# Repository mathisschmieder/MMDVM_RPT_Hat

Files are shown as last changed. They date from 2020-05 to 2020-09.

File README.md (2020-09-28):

# MMDVM_RPT_Hat
MMDVM_RPT_Hat for the Raspberry Pi

This project provides a Raspberry Pi Hat for the [MMDVM](https://github.com/g4klx/MMDVM).

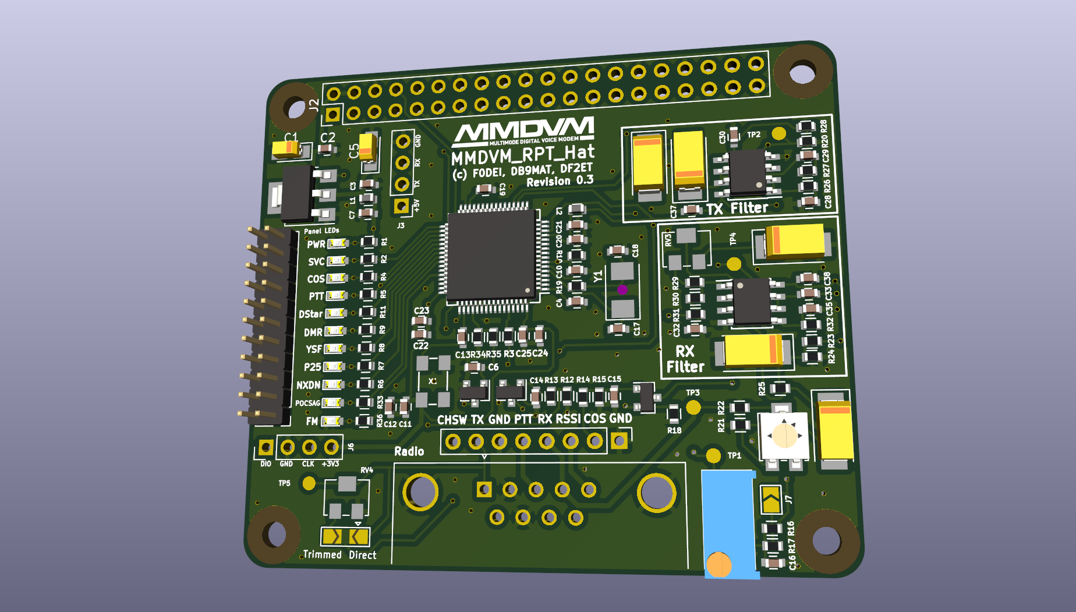
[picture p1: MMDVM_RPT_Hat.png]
PCB


## Revisions

### Revision 0.1
First PCB built for testing purposes.

### Revision 0.2
A second MOSFET transitor has been added to allow for channel switching by the MMDVM.

### Revision 0.3
Another LED was added for the latest implementation of FM mode.

## BOM
* The BOM for the rev0.1 board is available as [Mouser cart](https://www.mouser.com/ProjectManager/ProjectDetail.aspx?AccessID=13f81d64ff).
* [Mouser cart](https://www.mouser.com/ProjectManager/ProjectDetail.aspx?AccessID=fb0666986e) for rev0.2 board.
* Here is the [Mouser cart](https://www.mouser.com/ProjectManager/ProjectDetail.aspx?AccessID=3737004138) for the revision 0.3.

## License
This project is released under the Creative Commons Attribution-NonCommercial-ShareAlike 3.0 (CC-BY-NC-SA 3.0, https://creativecommons.org/licenses/by-nc-sa/3.0/) license. You may edit and share it as you like, as long as credit is given and the license is not changed. You can build as many boards for you and your friends as you like and you can even sell it to them to cover your costs, **however it is strictly forbidden to turn this into a commercial product! You are not allowed to build and sell these boards for profit!**

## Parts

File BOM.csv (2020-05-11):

Refs | Value | Footprint | QTY | MFR | MPN | SPR | SPN
C37;C38;C2;C3;C21;C22;C24;C10;C13;C12;C16;C4 | 100n | Capacitors_SMD:C_0603 | 12 | KEMET | C0603T104K3RALTU | Mouser | 80-C0603T104K3RALTU
C32;C28 | 10n | Capacitors_SMD:C_0603 | 2 | KEMET | C0603C103K2RECTU | Mouser | 80-C0603C103K2REC
C7 | 10u | Capacitors_SMD:C_0603 | 1 | KEMET | C0603C106M7PACTU | Mouser | 80-C0603C106M7P
C35;C30 | 1n | Capacitors_SMD:C_0603 | 2 | KEMET | C0603S102K4RACTU | Mouser | 80-C0603S102K4R
C17;C18 | 20p | Capacitors_SMD:C_0603 | 2 | KEMET | C0603C200K4GACTU | Mouser | 80-C0603C200K4G
C33;C29 | 39n | Capacitors_SMD:C_0603 | 2 | KEMET | C0603C393K4RACTU | Mouser | 80-C0603C393K4R
C14;C15;C6 | 470p | Capacitors_SMD:C_0603 | 3 | KEMET | C0603C471K4RACTU | Mouser | 80-C0603C471K4R
C20;C23;C25;C19;C11 | 4u7 | Capacitors_SMD:C_0603 | 5 | Murata Electronics | GRM188R61C475KAAJD | Mouser | 81-GRM188R61C475KAJD
C26;C27;C31;C34;C36 | 47u | Capacitors_Tantalum_SMD:CP_EIA-6032-28_Kemet-C | 5 | AVX | TAJC476K016SNJ | Mouser | 581-TAJC476K016SNJ
C1;C5 | 10u | Capacitors_Tantalum_SMD:CP_Tantalum_Case-A_EIA-3216-18_Reflow | 2 | AVX | F931C106KAA | Mouser | 647-F931C106KAA
J7 | GS2 | Connectors:GS2 | 1
J8 | GS3 | Connectors:GS3 | 1
J1 | Radio | Connectors_DSub:DSUB-9_Male_Horizontal_Pitch2.77x2.84mm_EdgePinOffset4.94mm_Housed_MountingHolesOffset7.48mm | 1 | TE Connectivity / AMP | 1734354-1 | Mouser | 571-1734354-1
Y1 | 8 MHz | Crystals:Crystal_SMD_Abracon_ABM3-2pin_5.0x3.2mm | 1 | ABRACON | ABM3-8.000MHz-D2Y-T | Mouser | 815-ABM3-8-D2Y-T
U2 | STM32F722RETx | Housings_QFP:LQFP-64_10x10mm_Pitch0.5mm | 1 | STMicroelectronics | STM32F722RET6 | Mouser | 511-STM32F722RET6
U3;U4 | MCP6002 | Housings_SOIC:SOIC-8_3.9x4.9mm_Pitch1.27mm | 2 | Microchip Technology | MCP6002-E/SN | Mouser | 579-MCP6002-E/SN
L1 | 10u | Inductors_SMD:L_0603 | 1 | Murata Electronics | LQM18FN100M00D | Mouser | 81-LQM18FN100M00D
L2 | 600R, 500mA | Inductors_SMD:L_0603 | 1 | Wurth Electronics | 742863160 | Mouser | 710-742863160
D3 | COS | LEDs:LED_0603 | 1 | Kingbright | APT1608SYC | Mouser | 604-APT1608SYC
D8 | DMR | LEDs:LED_0603 | 1 | Kingbright | APT1608SYC | Mouser | 604-APT1608SYC
D9 | DSTAR | LEDs:LED_0603 | 1 | Kingbright | APT1608SGC | Mouser | 604-APT1608SGC
D5 | NXDN | LEDs:LED_0603 | 1 | Kingbright | APT1608VBC/D | Mouser | 604-APT1608VBC/D
D6 | P25 | LEDs:LED_0603 | 1 | Kingbright | APT1608SURCK | Mouser | 604-APT1608SURCK
D10 | POCSAG | LEDs:LED_0603 | 1 | Kingbright | APT1608VBC/D | Mouser | 604-APT1608VBC/D
D4 | PTT | LEDs:LED_0603 | 1 | Kingbright | APT1608SURCK | Mouser | 604-APT1608SURCK
D1 | PWR | LEDs:LED_0603 | 1 | Kingbright | APT1608SGC | Mouser | 604-APT1608SGC
D2 | SVC | LEDs:LED_0603 | 1 | Kingbright | APT1608SURCK | Mouser | 604-APT1608SURCK
D7 | YSF | LEDs:LED_0603 | 1 | Kingbright | APT1608SECK | Mouser | 604-APT1608SECK
D11 | FM | LEDs:LED_0603 | 1 | Kingbright | APT1608VBC/D | Mouser | 604-APT1608VBC/D
TP3;TP4;TP2;TP5;TP1 | TEST | Measurement_Points:Measurement_Point_Round-SMD-Pad_Small | 5
J6 | STLink | Pin_Headers:Pin_Header_Straight_1x04_Pitch2.54mm | 1 | Wurth Electronics | 61300411121 | Mouser | 710-61300411121
J3 | Serial Display | Pin_Headers:Pin_Header_Straight_1x04_Pitch2.54mm | 1 | Wurth Electronics | 61300411121 | Mouser | 710-61300411121
J5 | Radio | Pin_Headers:Pin_Header_Straight_1x08_Pitch2.54mm | 1 | Wurth Electronics | 61300811121 | Mouser | 710-61300811121
J4 | Panel LEDs | Connector_PinHeader_2.00mm:PinHeader_2x11_P2.00mm_Vertical | 1 | Samtec | MTMM-111-09-L-D-380 | Mouser | 200-MTMM11109LD380
J2 | Raspberry_Pi_2_3 | Pin_Headers:Pin_Header_Straight_2x20_Pitch2.54mm | 1 | Harwin | M20-7832046 | Mouser | 855-M20-7832046
RV3 | 100k | Potentiometer_SMD:Potentiometer_Bourns_3214W_Vertical | 1 | Bourns | 3214W-1-104E | Mouser | 652-3214W-1-104E
RV4 | 200k | Potentiometer_SMD:Potentiometer_Bourns_3214W_Vertical | 1 | Bourns | 3214W-1-204E | Mouser | 652-3214W-1-204E
RV2 | 10k | Potentiometer_SMD:Potentiometer_Bourns_3314G_Vertical | 1 | Bourns | 3314G-1-103E | Mouser | 652-3314G-1-103E
RV1 | POT | Potentiometers:Potentiometer_Trimmer_Bourns_3296Y | 1 | Bourns | 3296Y-1-104LF | Mouser | 652-3296Y-1-104LF
R20;R3;R10 | 10k | Resistors_SMD:R_0603 | 3 | Panasonic | ERJ-PB3B1002V | Mouser | 667-ERJ-PB3B1002V
R19;R15 | 1M | Resistors_SMD:R_0603 | 2 | Panasonic | ERJ-3EKF1004V | Mouser | 667-ERJ-3EKF1004V
R21 | 1k | Resistors_SMD:R_0603 | 1 | Panasonic | ERJ-3EKF1001V | Mouser | 667-ERJ-3EKF1001V
R1;R2;R4;R5;R6;R7;R8;R9;R11;R33;R36 | 1k5 | Resistors_SMD:R_0603 | 11 | Panasonic | ERJ-3EKF1501V | Mouser | 667-ERJ-3EKF1501V
R22 | 20k | Resistors_SMD:R_0603 | 1 | Panasonic | ERJ-3EKF2002V | Mouser | 667-ERJ-3EKF2002V
R25;R23;R24 | 22k | Resistors_SMD:R_0603 | 3 | Panasonic | ERJ-P03F2202V | Mouser | 667-ERJ-P03F2202V
R29 | 30k | Resistors_SMD:R_0603 | 1 | Panasonic | ERJ-3EKF3002V | Mouser | 667-ERJ-3EKF3002V
R13;R14;R35 | 330 | Resistors_SMD:R_0603 | 3 | Panasonic | ERJ-U03F3300V | Mouser | 667-ERJ-U03F3300V
R16;R12;R18;R34 | 47k | Resistors_SMD:R_0603 | 4 | Panasonic | ERJ-3EKF4702V | Mouser | 667-ERJ-3EKF4702V
R31;R32;R27;R28;R17 | 4k7 | Resistors_SMD:R_0603 | 5 | Panasonic | ERJ-3EKF4701V | Mouser | 667-ERJ-3EKF4701V
R30;R26 | 5k1 | Resistors_SMD:R_0603 | 2 | Panasonic | ERJ-3EKF5101V | Mouser | 667-ERJ-3EKF5101V
U1 | LD1117S33TR | TO_SOT_Packages_SMD:SOT-223-3_TabPin2 | 1 | STMicroelectronics | LD1117S33TR | Mouser | 511-LD1117S33
Q2 | 2N7002 | TO_SOT_Packages_SMD:SOT-23 | 1 | ON Semiconductor / Fairchild | 2N7002 | Mouser | 512-2N7002
Q1;Q3 | IRLML2060 | TO_SOT_Packages_SMD:SOT-23 | 2 | Infineon Technologies | IRLML2060TRPBF | Mouser | 942-IRLML2060TRPBF
X1 | TCXO | lib:FOX-924B | 1 | Fox | FOX924B-12 | Mouser | 559-FOX924B-12

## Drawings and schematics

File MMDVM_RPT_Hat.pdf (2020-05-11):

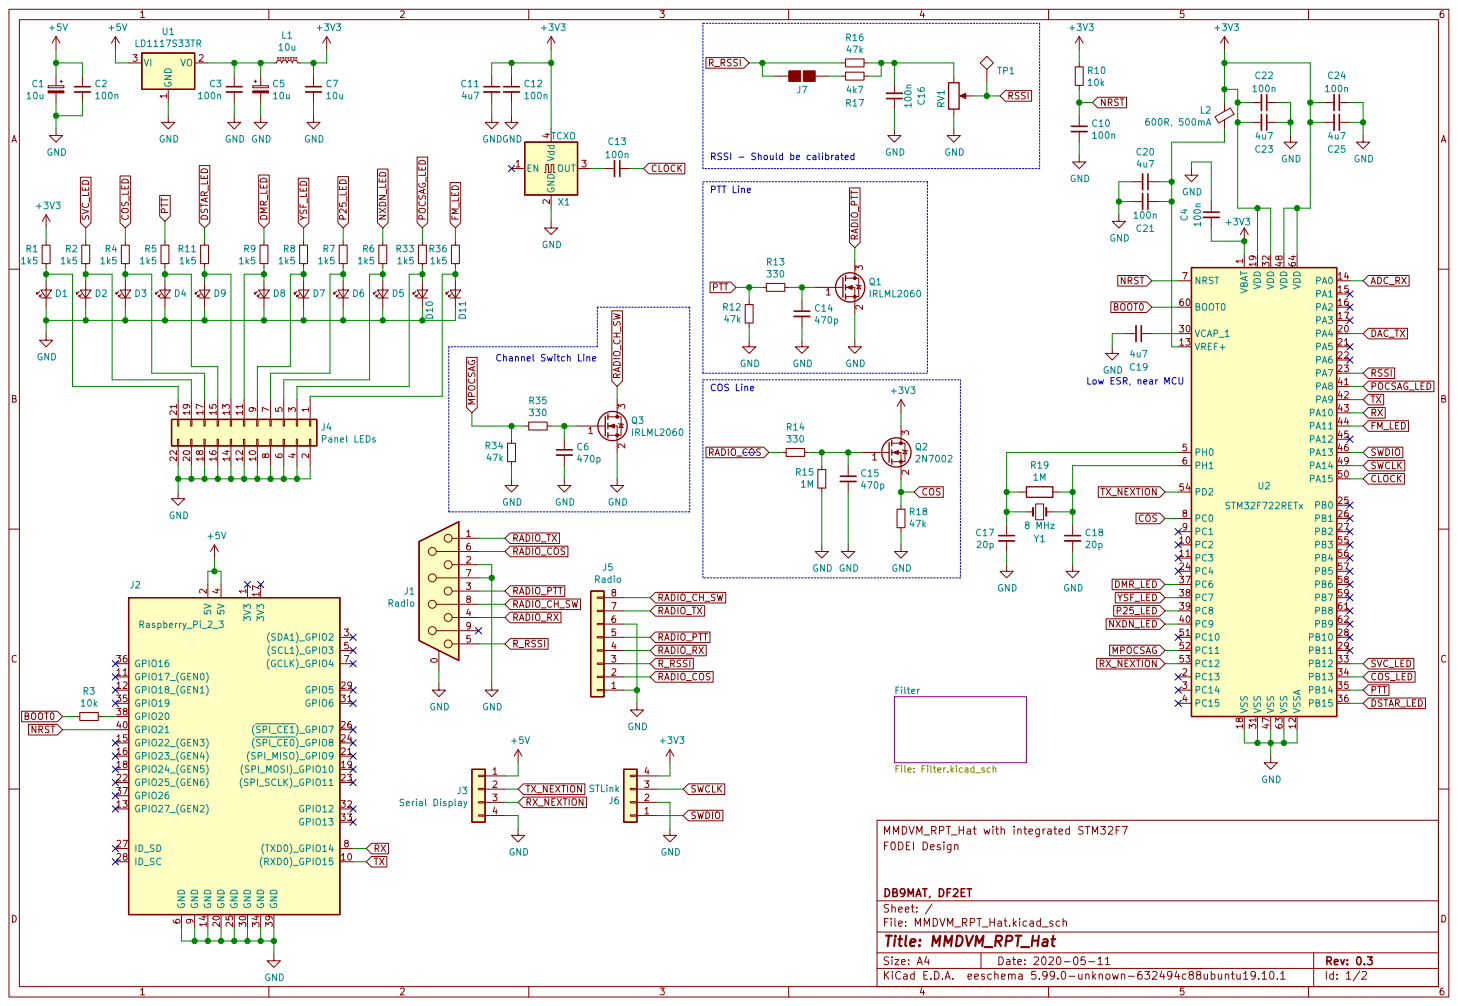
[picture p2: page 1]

1 PC2 10 PC3 11 VSSA 12 VREF+ 13 PA0 14 PA1 15 PA2 16 PA3 17 VSS 18 VDD 19 PC13 2 PA4 20 PA5 21 PA6 22 PA7 23 PC4 24 PB0 25 PB1 26 PB2 27 PB10 28 PB11 29 PC14 3 VCAP_1 30 VSS 31 VDD 32 PB12 33 PB13 34 PB14 35 PB15 36 PC6 37 PC7 38 PC8 39 PC15 4 PC9 40 PA8 41 PA9 42 PA10 43 PA11 44 PA12 45 PA13 46 VSS 47 VDD 48 PA14 49 PH0 5 PA15 50 PC10 51 PC11 52 PC12 53 PD2 54 PB3 55 PB4 56 PB5 57 PB6 58 PB7 59 PH1 6 BOOT0 60 PB8 61 PB9 62 VSS 63 VDD 64 NRST 7 PC0 8 PC1 9 U2 STM32F722RETx 1

Low ESR, near MCU COS Line

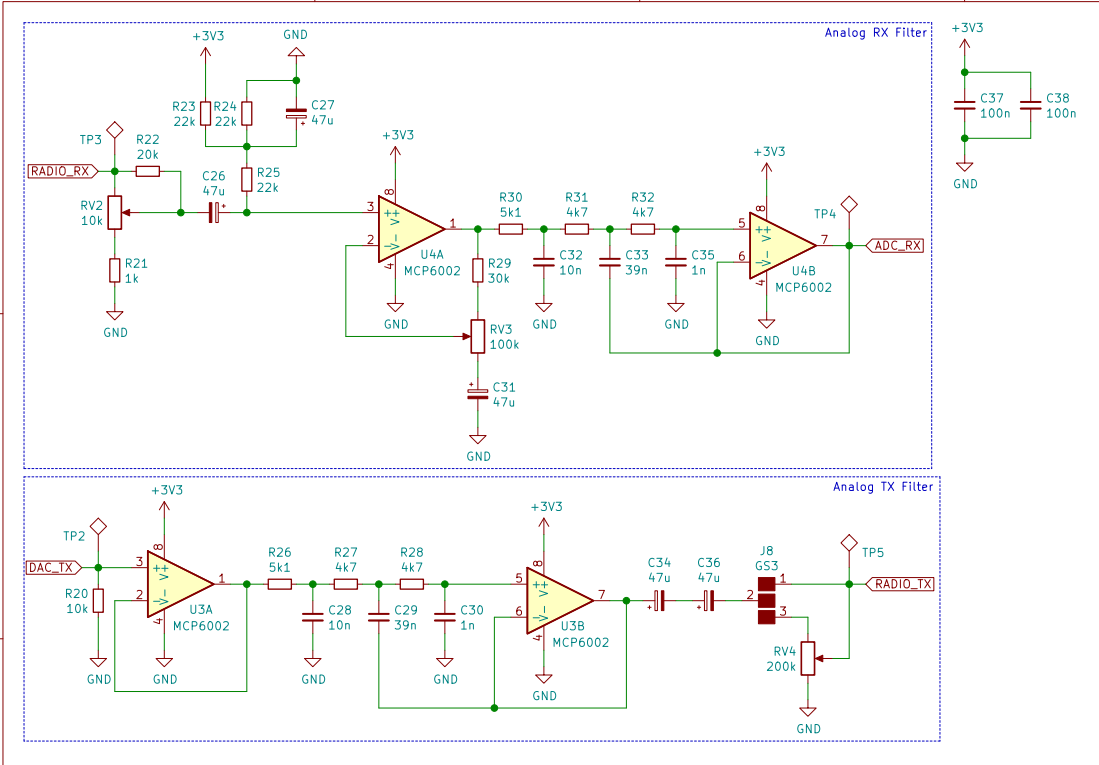
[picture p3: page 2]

File: Filter.kicad_sch Sheet: /Filter/ DB9MAT

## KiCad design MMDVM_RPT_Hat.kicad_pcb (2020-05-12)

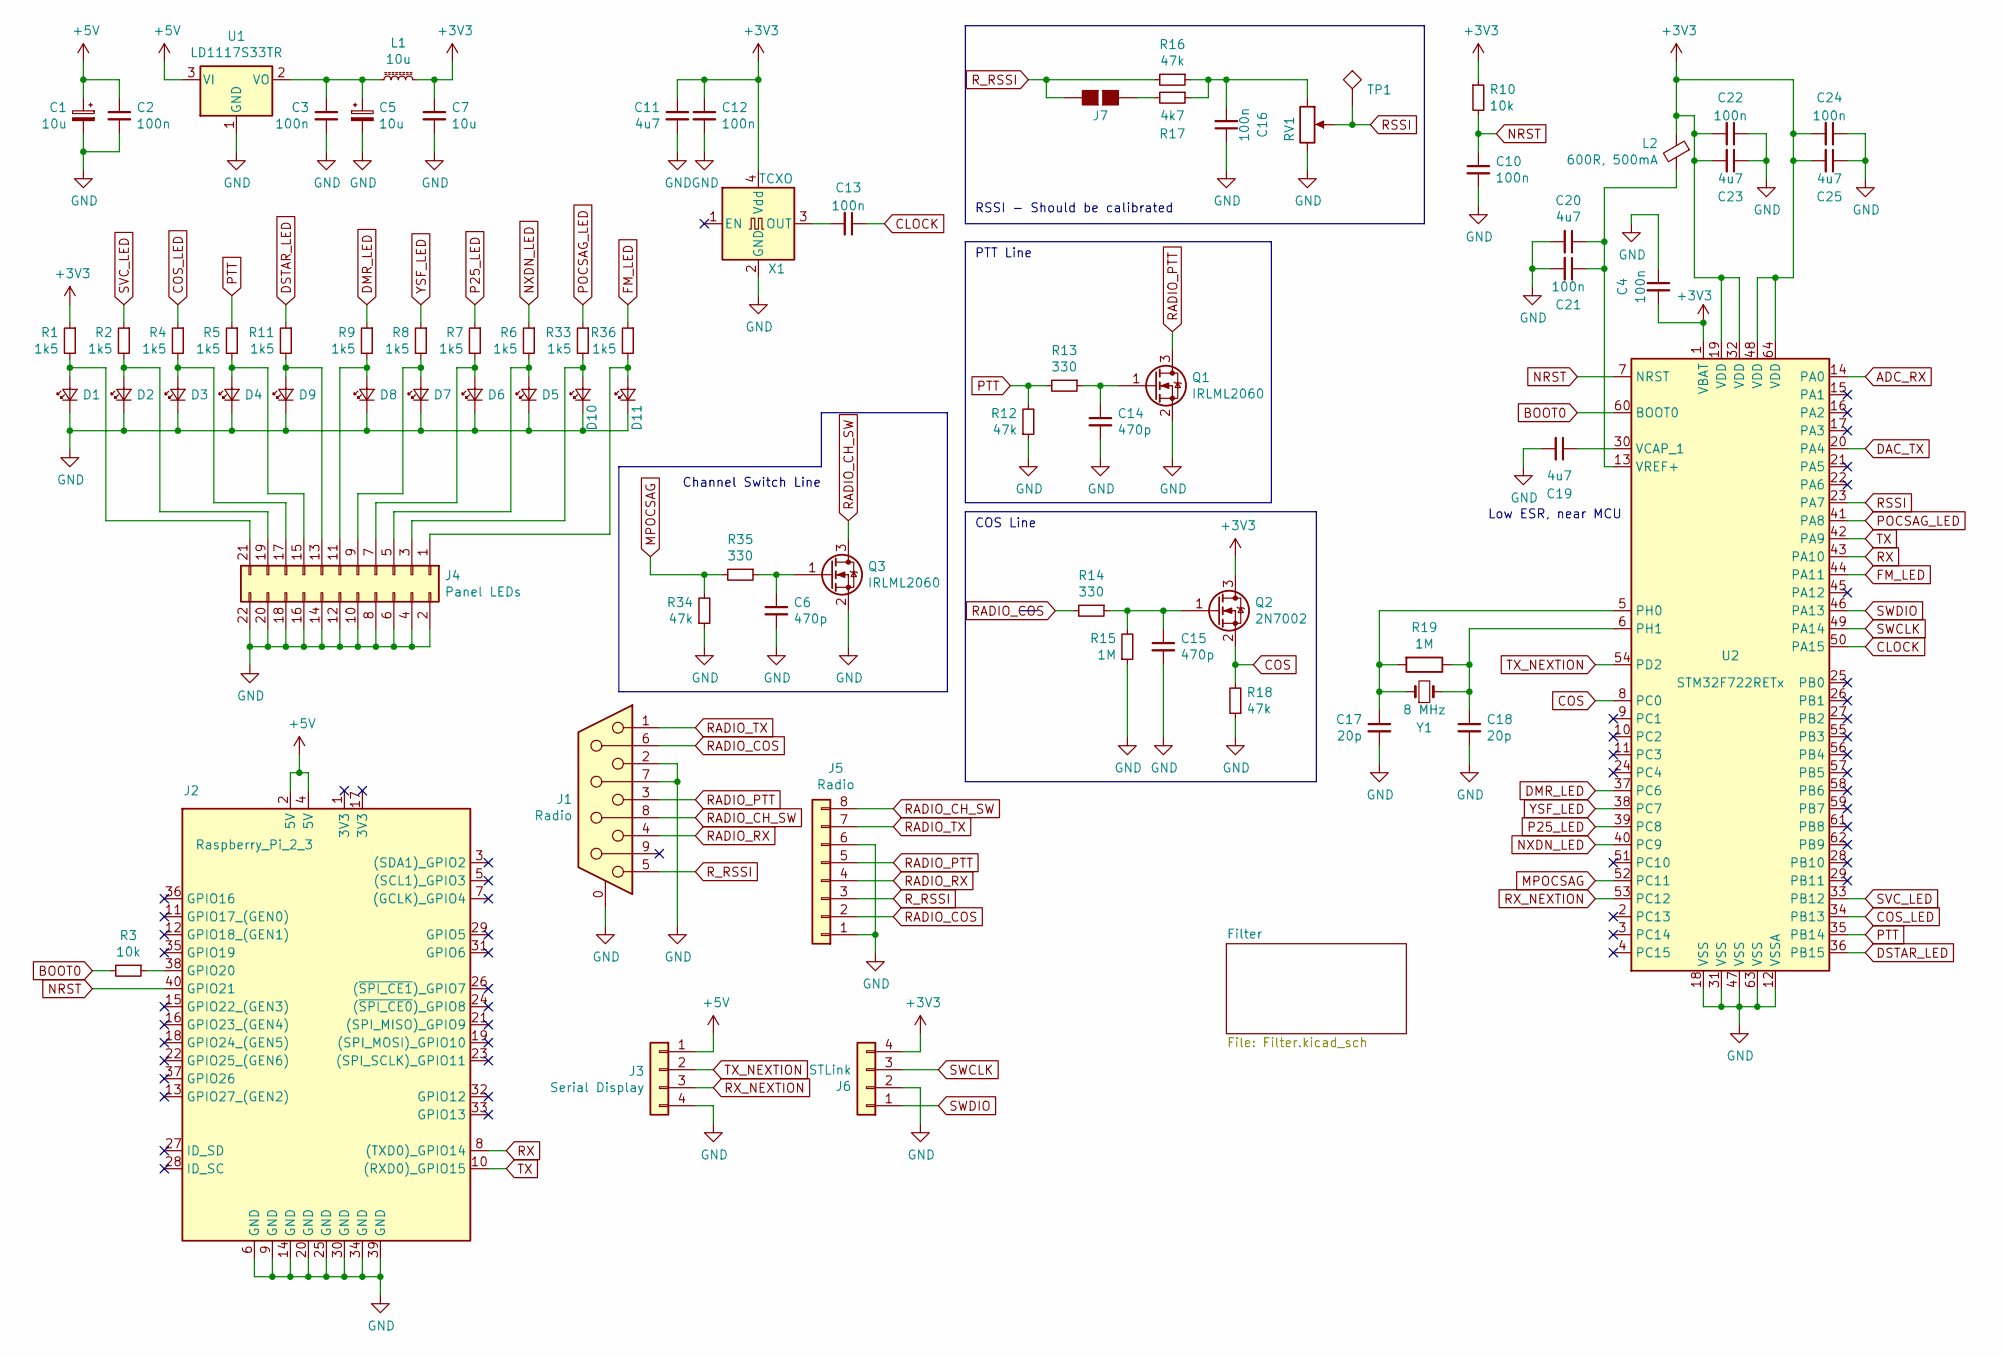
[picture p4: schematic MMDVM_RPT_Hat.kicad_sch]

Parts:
C1, C5: 10u; CP_Tantalum_Case-A_EIA-3216-18_Reflow; MPN F931C106KAA
C2, C3, C4, C10, C12, C13, C16, C21, C22, C24: 100n; C_0603; MPN C0603T104K3RALTU
C6, C14, C15: 470p; C_0603; MPN C0603C471K4RACTU
C7: 10u; C_0603; MPN C0603C106M7PACTU
C11, C19, C20, C23, C25: 4u7; C_0603; MPN GRM188R61C475KAAJD
C17, C18: 20p; C_0603; MPN C0603C200K4GACTU
D1: PWR; LED_0603; MPN APT1608SGC
D2: SVC; LED_0603; MPN APT1608SURCK
D3: COS; LED_0603; MPN APT1608SYC
D4: PTT; LED_0603; MPN APT1608SURCK
D5: NXDN; LED_0603; MPN APT1608VBC/D
D6: P25; LED_0603; MPN APT1608SURCK
D7: YSF; LED_0603; MPN APT1608SECK
D8: DMR; LED_0603; MPN APT1608SYC
D9: DSTAR; LED_0603; MPN APT1608SGC
D10: POCSAG; LED_0603; MPN APT1608VBC/D
D11: FM; LED_0603; MPN APT1608VBC/D
J1: Radio; DSUB-9_Male_Horizontal_Pitch2.77x2.84mm_EdgePinOffset4.94mm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; MPN 1734354-1
J2: Raspberry_Pi_2_3; Pin_Header_Straight_2x20_Pitch2.54mm; MPN M20-7832046
J3: Serial Display; Pin_Header_Straight_1x04_Pitch2.54mm; MPN 61300411121
J4: Panel LEDs; PinHeader_2x11_P2.00mm_Vertical
J5: Radio; Pin_Header_Straight_1x08_Pitch2.54mm; MPN 61300811121
J6: STLink; Pin_Header_Straight_1x04_Pitch2.54mm; MPN 61300411121
J7: GS2
L1: 10u; L_0603; MPN LQM18FN100M00D
L2: 600R, 500mA; L_0603; MPN 742863160
Q1, Q3: IRLML2060; SOT-23; MPN IRLML2060TRPBF
Q2: 2N7002; SOT-23; MPN 2N7002
R1, R2, R4, R5, R6, R7, R8, R9, R11, R33, R36: 1k5; R_0603; MPN ERJ-3EKF1501V
R3, R10: 10k; R_0603; MPN ERJ-PB3B1002V
R12, R16, R18, R34: 47k; R_0603; MPN ERJ-3EKF4702V
R13, R14, R35: 330; R_0603; MPN ERJ-U03F3300V
R15, R19: 1M; R_0603; MPN ERJ-3EKF1004V
R17: 4k7; R_0603; MPN ERJ-3EKF4701V
RV1: POT; Potentiometer_Trimmer_Bourns_3296Y; MPN 3296Y-1-104LF
TP1: TEST; Measurement_Point_Round-SMD-Pad_Small
U1: LD1117S33TR; SOT-223-3_TabPin2; MPN LD1117S33TR
U2: STM32F722RETx; LQFP-64_10x10mm_Pitch0.5mm; MPN STM32F722RET6
X1: TCXO; FOX-924B; MPN FOX924B-12
Y1: 8 MHz; Crystal_SMD_Abracon_ABM3-2pin_5.0x3.2mm; MPN ABM3-8.000MHz-D2Y-T

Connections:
+3V3: C4.2, C7.1, C11.1, C12.1, C22.2, C23.2, C24.2, C25.2, J6.4, L1.2, L2.1, Q2.3 (D), R1.1, R10.1, U2.1 (VBAT), U2.19 (VDD), U2.32 (VDD), U2.48 (VDD), U2.64 (VDD), X1.4 (Vdd); also elsewhere on the board
+5V: C1.1, C2.1, J2.2 (5V), J2.4 (5V), J3.1, U1.3 (VI)
ADC_RX: U2.14 (PA0); also elsewhere on the board
BOOT0: R3.2, U2.60 (BOOT0)
CLOCK: C13.1, U2.50 (PA15)
COS: Q2.2 (S), R18.2, U2.8 (PC0)
COS_LED: R4.1, U2.34 (PB13)
DAC_TX: U2.20 (PA4); also elsewhere on the board
DMR_LED: R9.1, U2.37 (PC6)
DSTAR_LED: R11.1, U2.36 (PB15)
FM_LED: R36.1, U2.44 (PA11)
GND: C1.2, C2.2, C3.2, C4.1, C5.2, C6.2, C7.2, C10.2, C11.2, C12.2, C14.2, C15.2, C16.1, C17.2, C18.2, C19.2, C20.2, C21.2, C22.1, C23.1, C24.1, C25.1, D1.1 (K), D2.1 (K), D3.1 (K), D4.1 (K), D5.1 (K), D6.1 (K), D7.1 (K), D8.1 (K), D9.1 (K), D10.1 (K), D11.1 (K), J1.0 (PAD), J1.2, J1.7, J2.6 (GND), J2.9 (GND), J2.14 (GND), J2.20 (GND), J2.25 (GND), J2.30 (GND), J2.34 (GND), J2.39 (GND), J3.4, J4.2, J4.4, J4.6, J4.8, J4.10, J4.12, J4.14, J4.16, J4.18, J4.20, J4.22, J5.1, J5.6, J6.2, Q1.2 (S), Q3.2 (S), R12.1, R15.1, R18.1, R34.1, RV1.3, U1.1 (GND), U2.12 (VSSA), U2.18 (VSS), U2.31 (VSS), U2.47 (VSS), U2.63 (VSS), X1.2 (GND); also elsewhere on the board
MPOCSAG: R34.2, R35.2, U2.52 (PC11)
NRST: C10.1, J2.40 (GPIO21), R10.2, U2.7 (NRST)
NXDN_LED: R6.1, U2.40 (PC9)
unnamed: C3.1, C5.1, L1.1, U1.2 (VO)
unnamed: C6.1, Q3.1 (G), R35.1
unnamed: C13.2, X1.3 (OUT)
unnamed: C14.1, Q1.1 (G), R13.1
unnamed: C15.1, Q2.1 (G), R14.1, R15.2
unnamed: C16.2, R16.1, R17.1, RV1.1
unnamed: C17.1, R19.2, U2.5 (PH0), Y1.1
unnamed: C18.1, R19.1, U2.6 (PH1), Y1.2
unnamed: C19.1, U2.30 (VCAP_1)
unnamed: C20.1, C21.1, L2.2, U2.13 (VREF+)
unnamed: D1.2 (A), J4.21, R1.2
unnamed: D2.2 (A), J4.19, R2.2
unnamed: D3.2 (A), J4.17, R4.2
unnamed: D4.2 (A), J4.15, R5.2
unnamed: D5.2 (A), J4.5, R6.2
unnamed: D6.2 (A), J4.7, R7.2
unnamed: D7.2 (A), J4.9, R8.2
unnamed: D8.2 (A), J4.11, R9.2
unnamed: D9.2 (A), J4.13, R11.2
unnamed: D10.2 (A), J4.3, R33.2
unnamed: D11.2 (A), J4.1, R36.2
unnamed: J2.38 (GPIO20), R3.1
unnamed: J7.1 (G1), R17.2
P25_LED: R7.1, U2.39 (PC8)
POCSAG_LED: R33.1, U2.41 (PA8)
PTT: R5.1, R12.2, R13.2, U2.35 (PB14)
RADIO_CH_SW: J1.8, J5.8, Q3.3 (D)
RADIO_COS: J1.6, J5.2, R14.2
RADIO_PTT: J1.3, J5.5, Q1.3 (D)
RADIO_RX: J1.4, J5.4; also elsewhere on the board
RADIO_TX: J1.1, J5.7; also elsewhere on the board
RSSI: RV1.2, TP1.1, U2.23 (PA7)
RX: J2.8 ((TXD0)_GPIO14), U2.43 (PA10)
RX_NEXTION: J3.3, U2.53 (PC12)
R_RSSI: J1.5, J5.3, J7.2 (G2), R16.2
SVC_LED: R2.1, U2.33 (PB12)
SWCLK: J6.3, U2.49 (PA14)
SWDIO: J6.1, U2.46 (PA13)
TX: J2.10 ((RXD0)_GPIO15), U2.42 (PA9)
TX_NEXTION: J3.2, U2.54 (PD2)
YSF_LED: R8.1, U2.38 (PC7)

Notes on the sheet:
Channel Switch Line
RSSI - Should be calibrated
PTT Line
COS Line
Low ESR, near MCU

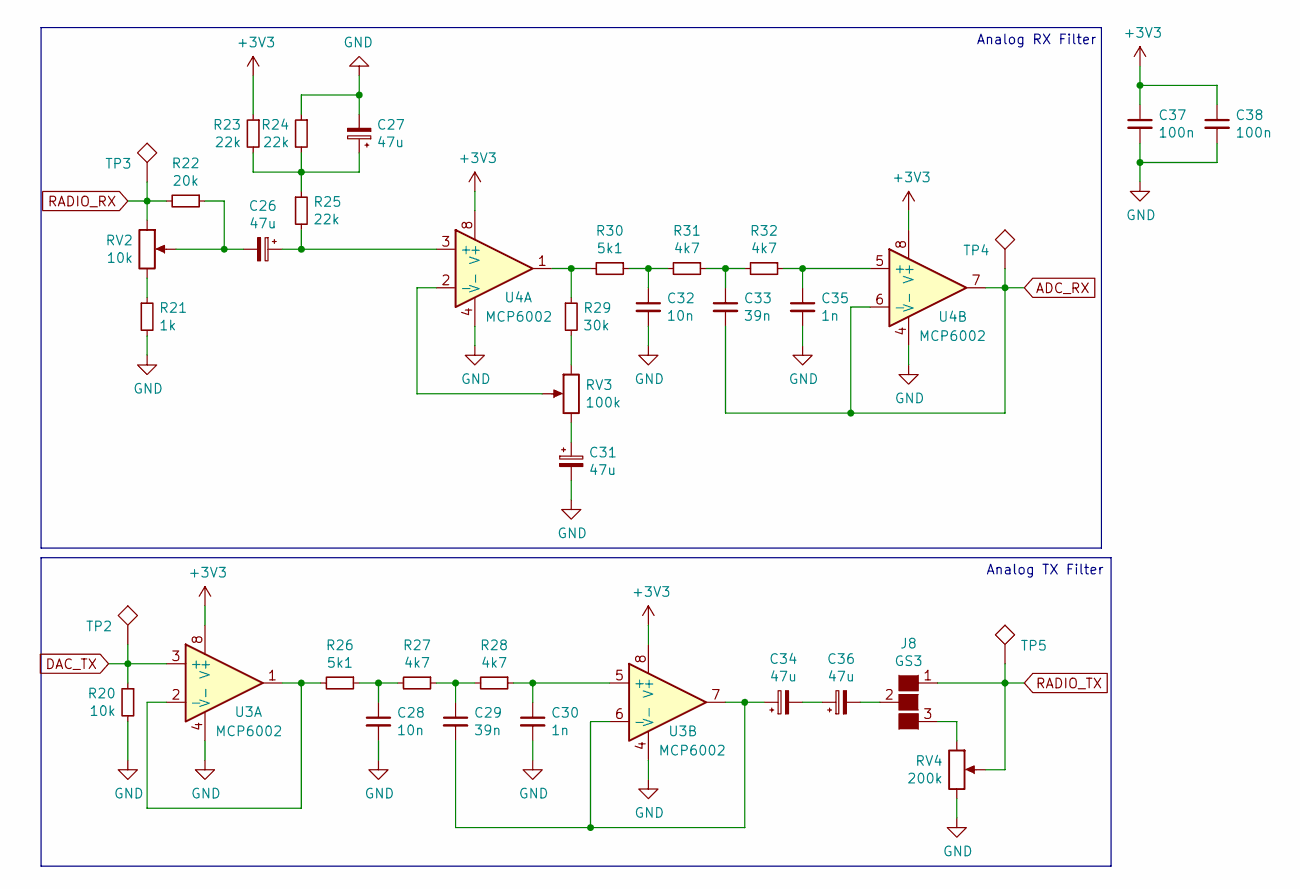
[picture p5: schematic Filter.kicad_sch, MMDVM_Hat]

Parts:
C26, C27, C31, C34, C36: 47u; CP_EIA-6032-28_Kemet-C; MPN TAJC476K016SNJ
C28, C32: 10n; C_0603; MPN C0603C103K2RECTU
C29, C33: 39n; C_0603; MPN C0603C393K4RACTU
C30, C35: 1n; C_0603; MPN C0603S102K4RACTU
C37, C38: 100n; C_0603; MPN C0603T104K3RALTU
J8: GS3
R20: 10k; R_0603; MPN ERJ-PB3B1002V
R21: 1k; R_0603; MPN ERJ-3EKF1001V
R22: 20k; R_0603; MPN ERJ-3EKF2002V
R23, R24, R25: 22k; R_0603; MPN ERJ-P03F2202V
R26, R30: 5k1; R_0603; MPN ERJ-3EKF5101V
R27, R28, R31, R32: 4k7; R_0603; MPN ERJ-3EKF4701V
R29: 30k; R_0603; MPN ERJ-3EKF3002V
RV2: 10k; Potentiometer_Bourns_3314G_Vertical; MPN 3314G-1-103E
RV3: 100k; Potentiometer_Bourns_3214W_Vertical; MPN 3214W-1-104E
RV4: 200k; Potentiometer_Bourns_3214W_Vertical; MPN 3214W-1-204E
TP2, TP3, TP4, TP5: TEST; Measurement_Point_Round-SMD-Pad_Small
U3, U4: MCP6002; SOIC-8_3.9x4.9mm_Pitch1.27mm; MPN MCP6002-E/SN

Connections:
+3V3: C37.1, C38.1, R23.1, U3.8 (V+), U4.8 (V+); also elsewhere on the board
ADC_RX: C33.2, TP4.1, U4.6 (-), U4.7; also elsewhere on the board
DAC_TX: R20.1, TP2.1, U3.3 (+); also elsewhere on the board
GND: C27.2, C28.2, C30.2, C31.2, C32.2, C35.2, C37.2, C38.2, R20.2, R21.2, R24.1, RV4.3, U3.4 (V-), U4.4 (V-); also elsewhere on the board
unnamed: C26.1, R25.2, U4.3 (+)
unnamed: C26.2, R22.1, RV2.2
unnamed: C27.1, R23.2, R24.2, R25.1
unnamed: C28.1, R26.1, R27.2
unnamed: C29.1, R27.1, R28.2
unnamed: C29.2, C34.1, U3.6 (-), U3.7
unnamed: C30.1, R28.1, U3.5 (+)
unnamed: C31.1, RV3.3
unnamed: C32.1, R30.1, R31.2
unnamed: C33.1, R31.1, R32.2
unnamed: C34.2, C36.1
unnamed: C35.1, R32.1, U4.5 (+)
unnamed: C36.2, J8.2 (G2)
unnamed: J8.3 (G3), RV4.1
unnamed: R21.1, RV2.3
unnamed: R26.2, U3.1, U3.2 (-)
unnamed: R29.1, R30.2, U4.1
unnamed: R29.2, RV3.1
unnamed: RV3.2, U4.2 (-)
RADIO_RX: R22.2, RV2.1, TP3.1; also elsewhere on the board
RADIO_TX: J8.1 (G1), RV4.2, TP5.1; also elsewhere on the board

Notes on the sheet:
Analog RX Filter
Analog TX Filter

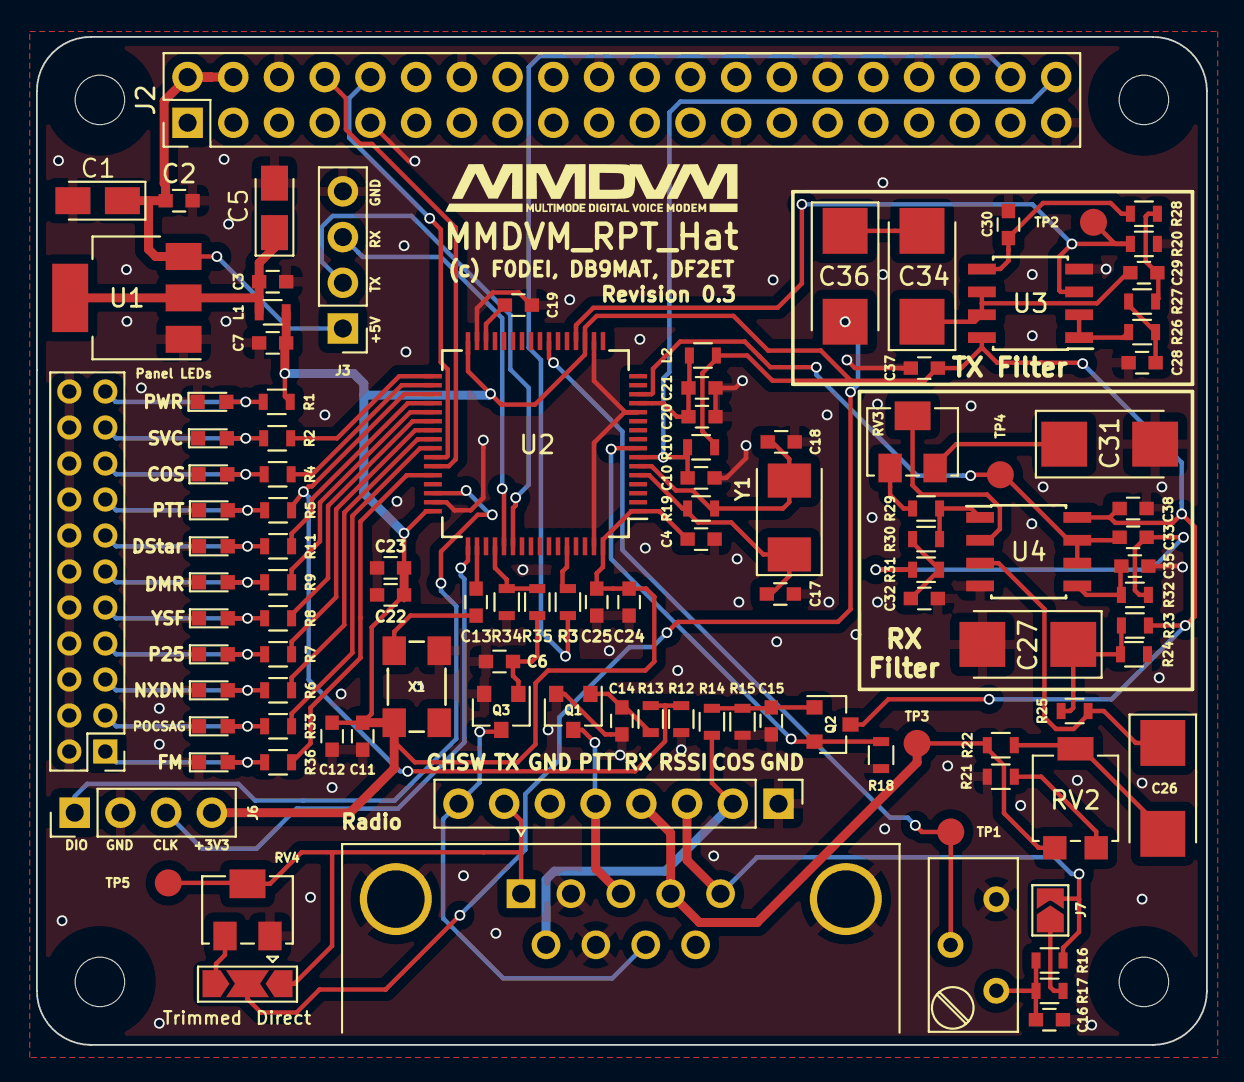
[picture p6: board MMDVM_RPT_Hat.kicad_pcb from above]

Board: 2 copper layers, 65.0 x 56.0 mm, 111 parts (0 on the bottom side), 75 nets.

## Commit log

2018-06-26 Revision 0.1
    [MMDVM_Hat-B.Cu.gbl, MMDVM_Hat-B.Mask.gbs, MMDVM_Hat-B.SilkS.gbo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]
2018-06-29 Add value for R19 and BOM
    [BOM.csv, BOM.xlsx, Filter.sch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]
2018-06-29 Correct part for 10nF capacitors
    [BOM.csv, BOM.xlsx, Filter.sch]
2018-06-30 Change Case code for 47u caps
    [BOM.csv, BOM.xlsx, Filter.sch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]
2018-07-23 Re-add lost C4
    [BOM.csv, BOM.xlsx, MMDVM_Hat.kicad_pcb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]
2018-07-24 Add Channel switch line (schematic only)
    [Filter.sch, MMDVM_Hat.sch]
2018-07-24 Use FET for channel switch
    [MMDVM_Hat.sch]
2018-07-24 Update netlist
    [MMDVM_Hat.sch]
2018-07-24 Revision 0.2: Added FET for channel switching; Rename to MMDVM_RPT_Hat
    [Filter.sch, MMDVM_Hat.kicad_pcb, MMDVM_Hat.sch]
2018-07-24 Aligned radio connector
    [MMDVM_Hat.kicad_pcb]
2018-07-24 Added more GND vias
    [MMDVM_Hat.kicad_pcb]
2018-07-24 Update BOM and README for rev0.2
    [BOM.csv, BOM.xlsx, Filter.sch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]
2020-05-11 Update PCB layout to rev0.3
    [BOM.csv, BOM.xlsx, Filter.kicad_sch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]
2020-05-11 Re-add OSHW and KiCad logos as well as drill file
    [MMDVM_RPT_Hat.kicad_pcb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]
2020-05-11 Add drill file
    [MMDVM_RPT_Hat.drl]
2020-05-12 Forgot to include the Mask layer in gerbers ... :/
    [MMDVM_RPT_Hat-B_Cu.gbl, MMDVM_RPT_Hat-B_Mask.gbs, MMDVM_RPT_Hat-B_Paste.gbp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]
